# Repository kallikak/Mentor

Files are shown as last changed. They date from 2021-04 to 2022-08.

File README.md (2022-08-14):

# Constructive Synthesis Mentor

A complete single board polyphonic synthesiser based on a Teensy 4.0 and Teensy Audio Shield. Called Mentor due to its focus as an instrument for learning subtractive synthesis. <a href="http://thewessens.net/synthbook/#constructive-synthesis">Constructive Synthesis</a> is the associated website covering the basics for learning subtractive synthesis.

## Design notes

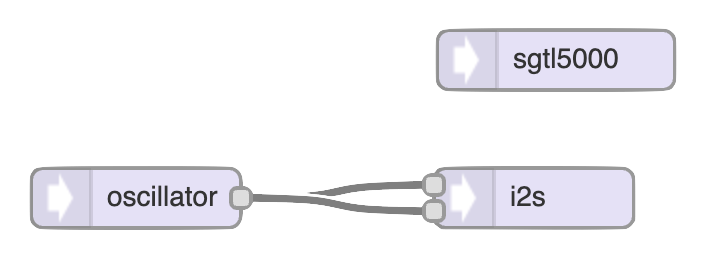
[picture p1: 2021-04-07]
teensy/SimpleOscillator.png

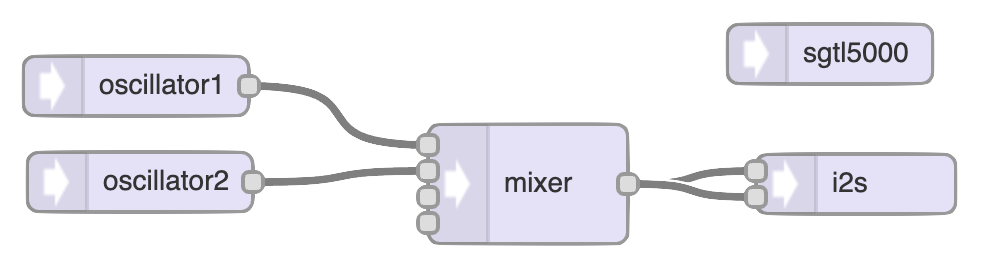
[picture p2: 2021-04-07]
teensy/Detune.png

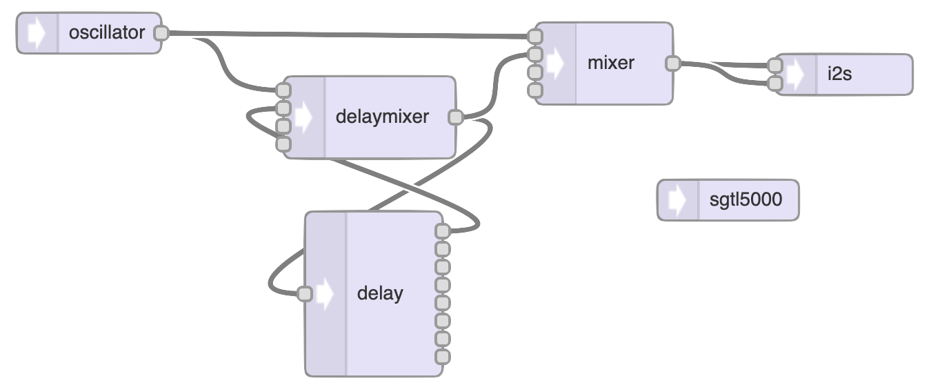
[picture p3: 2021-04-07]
teensy/Delay.png

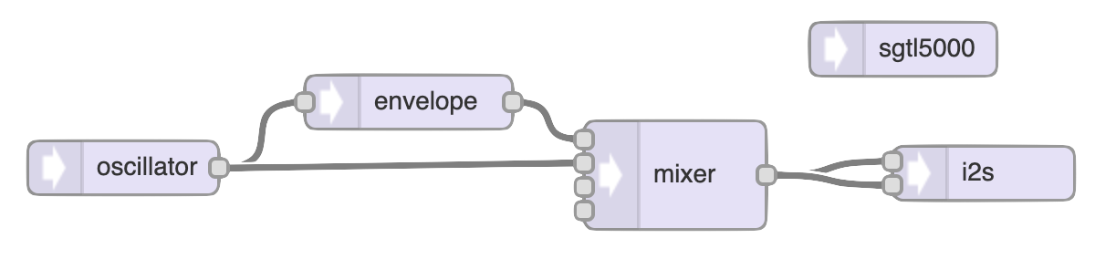
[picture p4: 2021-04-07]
teensy/ADSR.png

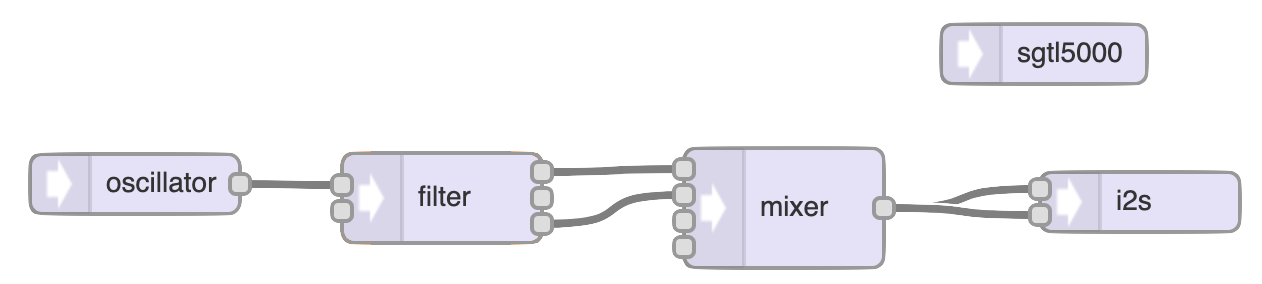
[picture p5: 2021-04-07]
teensy/Filter.png

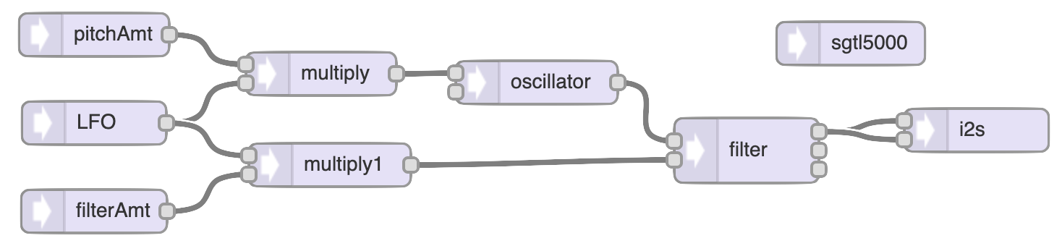
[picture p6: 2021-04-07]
teensy/LFO.png

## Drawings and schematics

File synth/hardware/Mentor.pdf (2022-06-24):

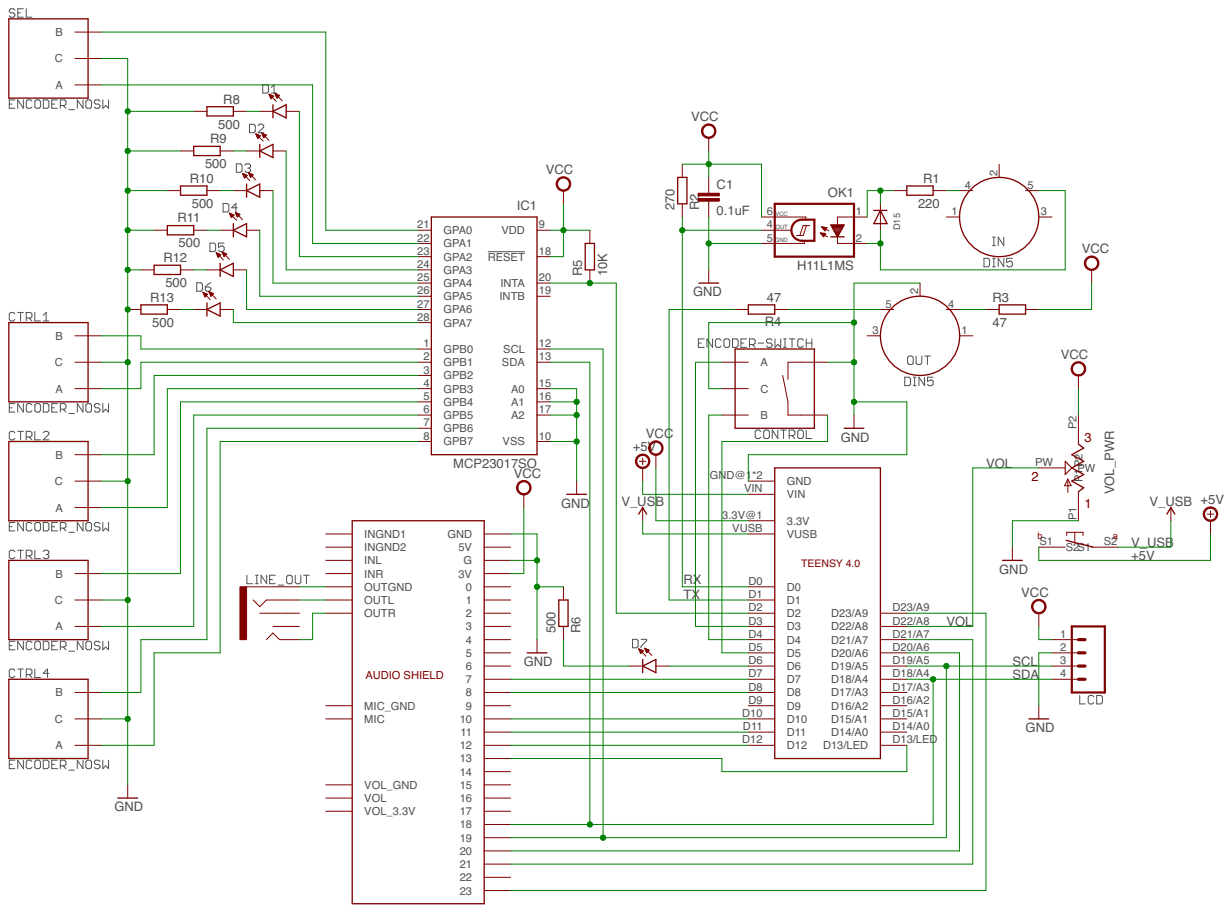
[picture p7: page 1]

VUSB

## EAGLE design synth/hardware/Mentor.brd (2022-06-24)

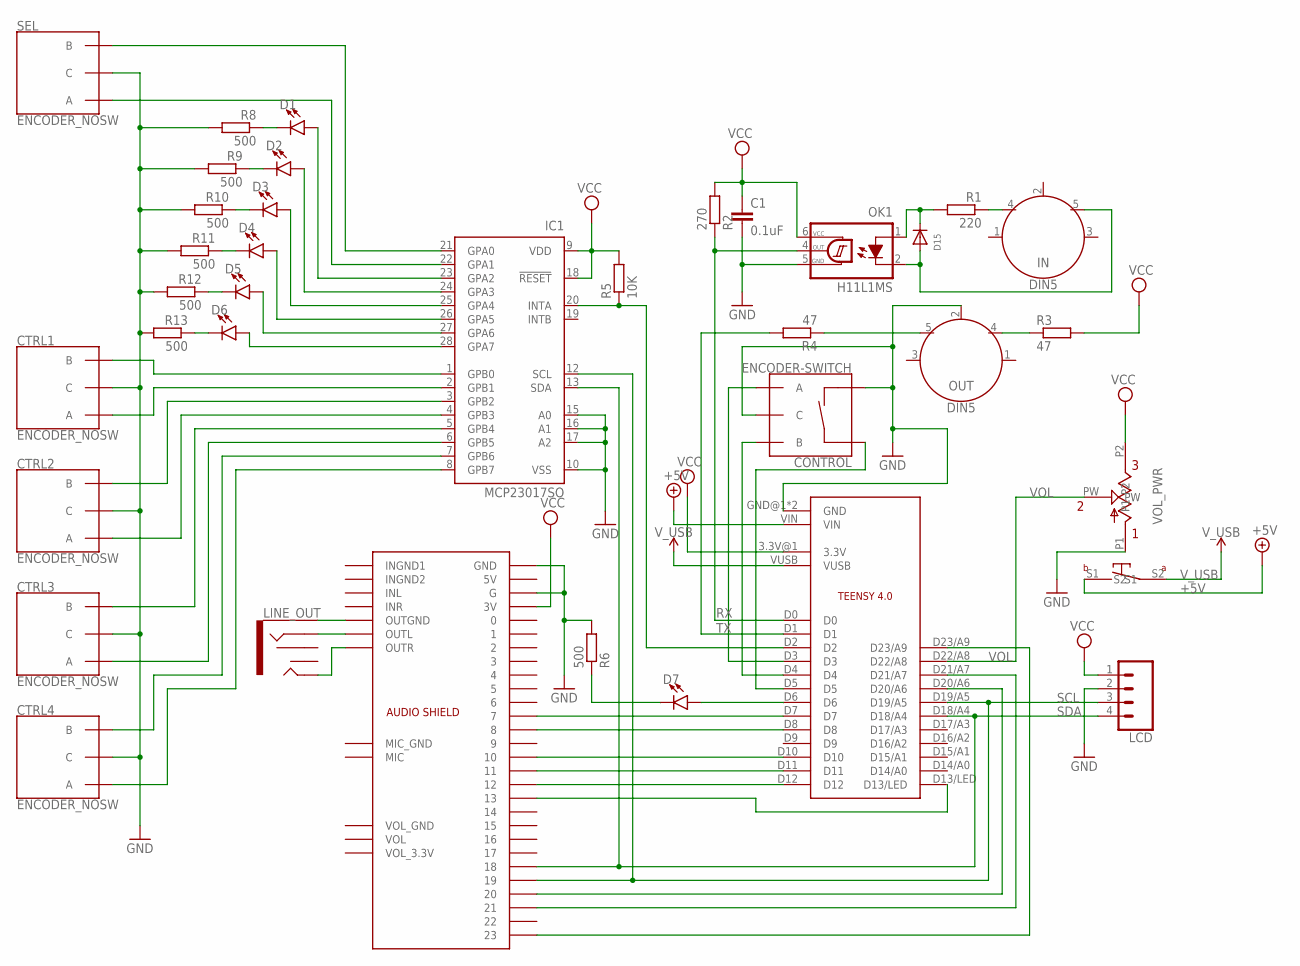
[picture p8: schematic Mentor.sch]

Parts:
C1: 0.1uF; C0603K
CONTROL: ENCODER-SWITCH; ROTARY_ENC_PLAIN
CTRL1, CTRL2, CTRL3, CTRL4: ENCODER_NOSW
D1, D2, D3, D4, D5, D6, D7: LED3MM; LED_3MM
D15: DIODESOD-123; SOD-123
IC1: MCP23017SO; SO28W
IN: DIN5; DIN5-RA-PTH
LCD: CONN_04LONGPADS; 1X04_LONGPADS
LINE_OUT: AUDIO_JACK_3.5MM_PTH; AUDIO-JACK
OK1: H11L1MS; DIL6-SMD
OUT: DIN5; DIN5-RA-PTH
R1: 220; R0603
R2: 270; R0603
R3, R4: 47; R0603
R5: 10K; R0603
R6, R8, R9, R10, R11, R12, R13: 500; R0603
SEL: ENCODER_NOSW
U$2: TEENSY4.0_SIMPLE
U$3: AUDIO SHIELD; AUDIOSHIELD
VOL_PWR: 10K; RK097-SINGLE-W/SWITCH

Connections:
+5V: U$2.VIN, VOL_PWR.S1
GND: C1.2, CONTROL.C, CONTROL.SW-, CTRL1.C, CTRL2.C, CTRL3.C, CTRL4.C, IC1.10 (VSS), IC1.15 (A0), IC1.16 (A1), IC1.17 (A2), LCD.2, OK1.5 (GND), OUT.2, R6.2, R8.2, R9.2, R10.2, R11.2, R12.2, R13.2, SEL.C, U$2.GND@1 (GND), U$2.GND@2 (GND), U$3.G, U$3.GND, VOL_PWR.P1
MISO: U$2.D12, U$3.12
MOSI: U$2.D11, U$3.11
unnamed: IC1.21 (GPA0), SEL.B
unnamed: IC1.22 (GPA1), SEL.A
unnamed: CTRL1.B, IC1.1 (GPB0)
unnamed: CTRL1.A, IC1.2 (GPB1)
unnamed: CTRL2.B, IC1.3 (GPB2)
unnamed: CTRL2.A, IC1.4 (GPB3)
unnamed: CTRL3.B, IC1.5 (GPB4)
unnamed: CTRL3.A, IC1.6 (GPB5)
unnamed: CTRL4.B, IC1.7 (GPB6)
unnamed: CTRL4.A, IC1.8 (GPB7)
unnamed: OUT.5, R4.1
unnamed: U$2.D20/A6, U$3.20
unnamed: U$2.D21/A7, U$3.21
unnamed: U$2.D23/A9, U$3.23
unnamed: U$2.D10, U$3.10
unnamed: U$2.D7, U$3.7
unnamed: U$2.D8, U$3.8
unnamed: IC1.20 (INTA), R5.1, U$2.D2
unnamed: D6.K (C), R13.1
unnamed: D1.K (C), R8.1
unnamed: D6.A, IC1.28 (GPA7)
unnamed: D7.K (C), R6.1
unnamed: D7.A, U$2.D6
unnamed: D2.K (C), R9.1
unnamed: D3.K (C), R10.1
unnamed: D3.A, IC1.25 (GPA4)
unnamed: CONTROL.A, U$2.D3
unnamed: CONTROL.B, U$2.D4
unnamed: CONTROL.SW+, U$2.D5
unnamed: D4.K (C), R11.1
unnamed: D5.K (C), R12.1
unnamed: D15.A, IN.5, OK1.2 (C)
unnamed: D15.C, OK1.1 (A), R1.2
unnamed: IN.4, R1.1
unnamed: LINE_OUT.SLEEVE, U$3.OUTGND
unnamed: OUT.4, R3.1
unnamed: LINE_OUT.RING, U$3.OUTL
unnamed: LINE_OUT.TIP, U$3.OUTR
RX: OK1.4 (OUT), R2.1, U$2.D0
SCK: U$2.D13/LED, U$3.13
SCL: IC1.12 (SCL), LCD.3, U$2.D19/A5, U$3.19
SDA: IC1.13 (SDA), LCD.4, U$2.D18/A4, U$3.18
SEL1: D1.A, IC1.23 (GPA2)
SEL2: D2.A, IC1.24 (GPA3)
SEL4: D4.A, IC1.26 (GPA5)
SEL5: D5.A, IC1.27 (GPA6)
TX: R4.2, U$2.D1
VCC: C1.1, IC1.9 (VDD), IC1.18 (!RESET), LCD.1, OK1.6 (VCC), R2.2, R3.2, R5.2, U$2.3.3V@1 (3.3V), U$3.3V, VOL_PWR.P2
VOL: U$2.D22/A8, VOL_PWR.PW
V_USB: U$2.VUSB, VOL_PWR.S2

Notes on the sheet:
AUDIO SHIELD

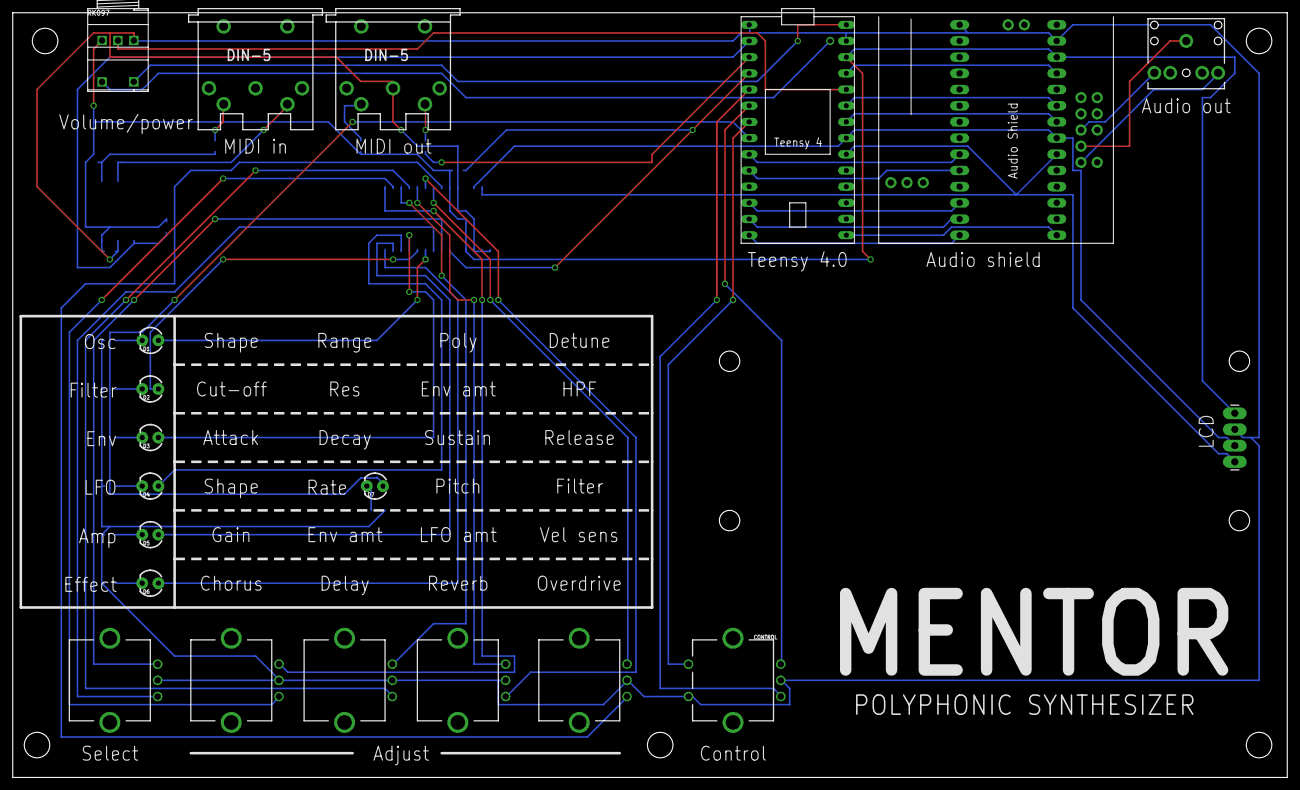
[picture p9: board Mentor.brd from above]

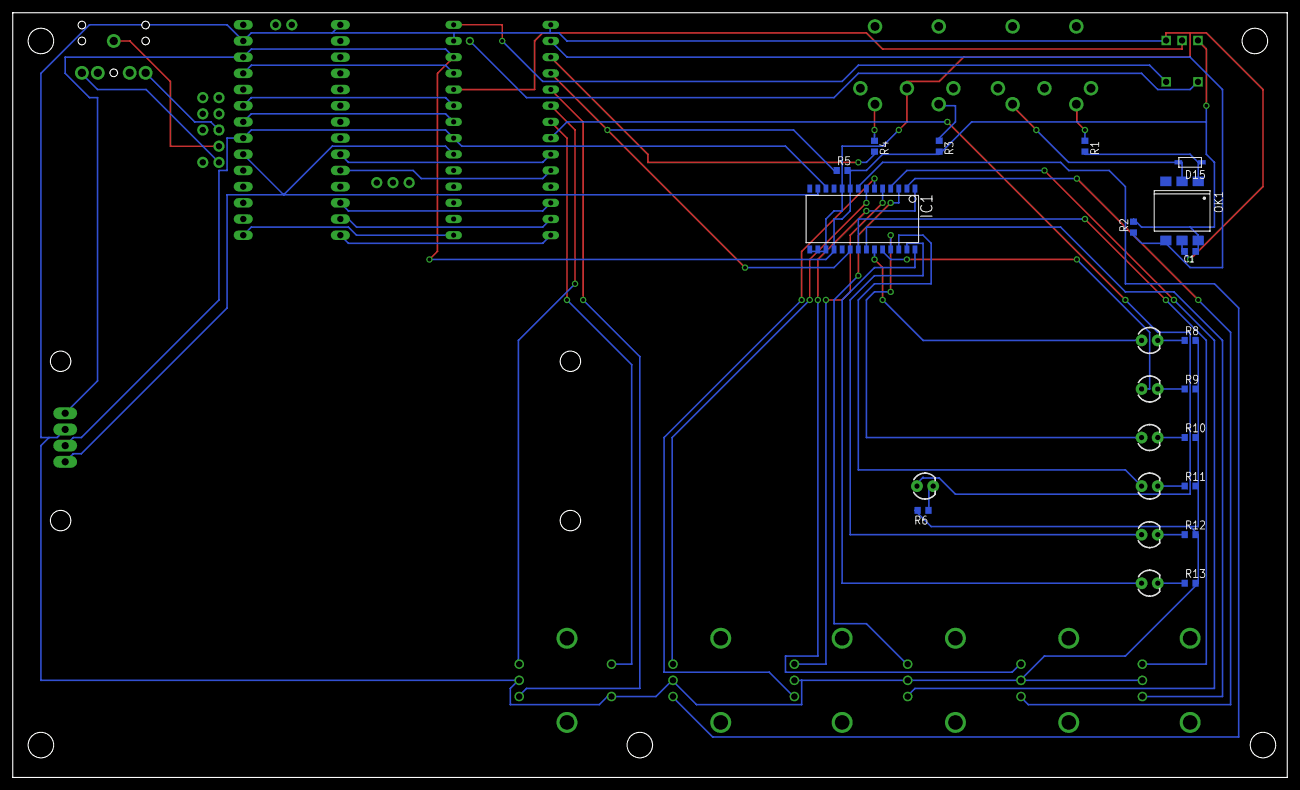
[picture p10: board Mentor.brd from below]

Board: 2 copper layers, 200.0 x 120.0 mm, 36 parts (16 on the bottom side), 54 nets.

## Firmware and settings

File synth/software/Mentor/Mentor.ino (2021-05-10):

#include <Wire.h>
#include <ctype.h>

#include "Config.h"
#include "Control.h"
#include "Controls.h"
#include "Demo.h"
#include "LCD.h"
#include "MIDIManager.h"
#include "Presets.h"
#include "Synth.h"
#include "Voice.h"

#define LFO_LED 6

Synth *synth;

void setup() 
{
  Serial.begin(9600);
  delay(1000);
  srand((analogRead(A0) << 10) + analogRead(A1));  // unused pins
  
  setupLCD();
  setupControls();
  setupControl();
  initDemo();
  
  pinMode(LFO_LED, OUTPUT);
  digitalWrite(LFO_LED, LOW);

  synth = new Synth();
  loadPreset(getSavedStartupPreset());
  delay(500);
  writeParamString(1, "Loading", getPresetName(getSavedStartupPreset()));
  delay(1000);
  synth->loadConfig(config);
  
  setupMIDI();
  printConfig(config);
  
  Serial.println("Setup done");
}

int loopcount = 0;
bool monitorlevel = false;
void monitorPeak();
void loop() 
{
  static bool led = false;
  checkControls(loopcount++);
  checkControl();
  
  if (monitorlevel && loopcount % 200 == 0)
  {
    monitorPeak();
  }
  
  checkMIDI();
  if (synth->checkFlashLFO())
  {
    led = !led;
    digitalWrite(LFO_LED, led);
  }
  checkDemo();
  if (Serial.available())
  {
    char c = Serial.read();
    if (iscntrl(c))
    {
      // ignore control data 
    }
    else if (c == 'p')
    {
      printConfig(config);
    }
    else if (c == '1')
    {
      Serial.println("Playing 1 note");
      playNote(55, 127);
    }
    else if (c == '2')
    {
      Serial.println("Playing 2 notes");
      playNote(55, 127);
      playNote(62, 127);
    }
    else if (c == '5')
    {
      Serial.println("Playing 5 notes");
      playNote(55, 127);
      playNote(59, 127);
      playNote(62, 127);
      playNote(67, 127);
      playNote(69, 127);
    }
    else if (c == '0')
    {
      Serial.println("Lifting notes");
      releaseNote(55);
      releaseNote(59);
      releaseNote(62);
      releaseNote(67);
      releaseNote(69);
    }
    else if (c == 'm')
    {
      Serial.print("Max memory usage: ");
      Serial.println(AudioMemoryUsageMax());
    }
    else if (c == 't')
    {
      Serial.print("MCU Temperature: ");
      Serial.println(tempmonGetTemp());
    }
    else if (c == 'v')
    {
      monitorlevel = !monitorlevel;
      Serial.print("Output level monitor ");
      Serial.println(monitorlevel ? "on" : "off");
    }
    else if (c == 'h')
    {
      Serial.println("========");
      Serial.println("Commands");
      Serial.println("========");
      Serial.println("p:\tPrint current config");
      Serial.println("m:\tPrint max audio memory usage");
      Serial.println("v:\tToggle output volume level monitor");
      Serial.println("t:\tPrint MCU temperature");
      Serial.println("h:\tPrint this message");
    }
    else if (c != '\r' && c != '\n' && !isspace(c))
    {
      Serial.println("Available commands: pmvth");
      Serial.println("Type h for help");
    }
    while (Serial.available())
      Serial.read();
  }
}

/*
 * BUGS
 *  - Something strange happens when amp env amount is 0
 * TODO
 *  - Refine levels
 */

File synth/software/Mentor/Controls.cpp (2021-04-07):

#include "Adafruit_MCP23017.h"
#include "Rotary.h"
#include <Bounce2mcp.h>

#include "Config.h"
#include "Controls.h"
#include "LCD.h"
#include "Utility.h"
#include "Synth.h"
#include "MIDIManager.h"

#define NUM_SELECT  6
class BounceMcp;

typedef struct
{
  int pinA;
  int pinB;
  uint16_t mask;
  bool halfstate;
  uint8_t _state;
  int minval[NUM_SELECT];
  int maxval[NUM_SELECT];
  BounceMcp *debouncer;
} encoder;

void setSelectLed(int led);
void showSelectSummary(int selected, bool addRow1);
void handleEncoderTurn(int i, int d);
void handleEncoderPress(int i);

int selected = 0;

#define SELECT_OSC  0
#define SELECT_FLT  1
#define SELECT_ENV  2
#define SELECT_LFO  3
#define SELECT_AMP  4
#define SELECT_EFF  5

int lastupdatemillis = 0;
bool summaryDone = false;

bool isFrequencyMode = false;
float droneFreq = 440;
  
Adafruit_MCP23017 *expander = NULL;

int selleds[] = { 2, 3, 4, 5, 6, 7 };

#define NUM_ENCODERS 6

encoder encoders[] = {
  { 0,  1, 0x0003, false, R_START, {0, 0, 0, 0, 0, 0}, {5, 5, 5, 5, 5, 5}, NULL },
  // Shape, Cutoff, Attack, LFO_Shape, Gain, Chorus
  { 8,  9, 0x0300, false, R_START, {0, 0, 0, 0, 0, 0}, {250, 127, 127, 6, 127, 15}, NULL },
  // Range, Res, Decay, Rate, Amp_Env_Amt, Delay
  {10, 11, 0x0700, false, R_START, {0, 0, 0, 0, 0, 0}, {3, 127, 127, 127, 127, 15}, NULL },
  // Poly, Flt_Env_Amt, Sustain, Pitch, LFO_Amt, Reverb
  {12, 13, 0x3000, false, R_START, {0, -63, 0, 0, 0, 0}, {POLYMAX, 64, 127, 127, 127, 15},  NULL },
  // Detune, HPF, Release, LFO_Flt, Vel_sens, Overdrive
  {14, 15, 0x7000, false, R_START, {0, 0, 0, 0, 0, 0}, {50, 127, 127, 127, 127, 15}, NULL }
};

#define SELECT_ENC 0

uint16_t blockMillis = 0;

void setupEncoders()
{
  int j;
  expander = new Adafruit_MCP23017();
  expander->begin((uint8_t)0);
  for (j = 0; j < NUM_ENCODERS; ++j)
  {
    encoder *enc = &encoders[j];
    expander->pinMode(enc->pinA, INPUT);
    expander->pullUp(enc->pinA, HIGH); // turn on a 100K pullup internally
    expander->pinMode(enc->pinB, INPUT);
    expander->pullUp(enc->pinB, HIGH); // turn on a 100K pullup internally
  }
  for (j = 0; j < NUM_SELECT; ++j)
  {
    int p = selleds[j];
    expander->pinMode(p, OUTPUT);
    expander->digitalWrite(p, LOW);
  }
}

static int lastencoder = -1;
static long lastencodermillis = -1;

#define MIN_ENC_TIME 50
#define MAX_ENC_TIME 200
#define MAX_ENC_ACCEL 16

void checkEncoders(unsigned long now)
{
  uint16_t vals = expander->readGPIOAB();
  for (int i = 0; i < NUM_ENCODERS; ++i)
  {
    encoder *e = &encoders[i]; 
    uint16_t val = vals;
    val >>= e->pinA;
    int p0 = val & 0x0001;
    int p1 = (val & 0x0002) >> 1;
    uint8_t pinstate = (p1 << 1) | p0;  
    if (e->halfstate)
      e->_state = ttable_half[e->_state & 0xf][pinstate];
    else
      e->_state = ttable[e->_state & 0xf][pinstate]; 
    int d;      
    if ((e->_state & 0x30) == DIR_CW)
      d = 1;
    else if ((e->_state & 0x30) == DIR_CCW)
      d = -1;
    else
      d = 0;

    if (d)
    {
      // add some acceleration for the encoders unless the value range is small
      bool accel = e->maxval[selected] - e->minval[selected] > 20;
      if (accel)
      {
        if (lastencoder != i)
        {
          lastencoder = i;
          lastencodermillis = -1;
        }
        else 
        {
          lastencoder = i;
          long delta = now - lastencodermillis;
          int factor;
          if (delta >= MAX_ENC_TIME)
            factor = 1;
          else if (delta <= MIN_ENC_TIME)
            factor = MAX_ENC_ACCEL;
          else
            factor = MAX_ENC_ACCEL - round(1.0 * (delta  - MIN_ENC_TIME) / (MAX_ENC_TIME - MIN_ENC_TIME) * (MAX_ENC_ACCEL - 1));
          d *= factor;
          lastencodermillis = now;
        }
      }
      handleEncoderTurn(i, d);
      lastupdatemillis = now;
      summaryDone = false;
    }
  }
}
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

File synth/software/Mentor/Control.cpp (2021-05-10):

#include <Bounce2.h>

#include "Config.h"
#include "Control.h"
#include "Controls.h"
#include "Demo.h"
#include "LCD.h"
#include "MIDIManager.h"
#include "Rotary.h"
#include "Presets.h"
#include "Synth.h"

#define CONTROL_A  3
#define CONTROL_B  4
#define CONTROL_SW 5
#define LONG_MILLIS 1000

typedef enum
{
  CTRL_PRESET,  // for loading ROM or user presets
  CTRL_USER,    // for saving user presets
  CTRL_MIDICLK, // toggling external clock
  CTRL_DEMO,    // play or stop demo
  CTRL_PANIC,   // all MIDI notes off
  CTRL_AFTERTOUCH
} control_state;
#define NUM_STATES 6
#define CTRL_LAST CTRL_AFTERTOUCH

void checkSwitch();
void controlClick();
void controlLongPress();
void controlTurned(int d, bool btnState);
void selectValue();
void selectState();

static control_state ctrl_state = CTRL_LAST;
static int ctrl_val = 0;
static bool state_selected = false;

static bool halfstate = false;
static uint8_t _state;

static Bounce debouncer = Bounce(); 
static long falltimeP = -1;
static bool longpressP = false;

int getLastStateValue()
{
  switch (ctrl_state)
  {
    case CTRL_PRESET:
      return getLastPresetIndex() + 1;
    case CTRL_MIDICLK:
      return synth->getLFOSync() + 1;
    case CTRL_USER:
      return getLastUserPresetIndex();
    case CTRL_DEMO:
      return demoIsPlaying() ? 1 : 0;
    case CTRL_AFTERTOUCH:
      return getAftertouch() ? 1 : 0;
    default:
      return 0;
  }
}

const char *getStateString(control_state state)
{
  switch (state)
  {
    case CTRL_PRESET:
      return "Presets";
    case CTRL_USER:
      return "Save";
    case CTRL_MIDICLK:
      return "LFO Sync";
    case CTRL_DEMO:
      return "Demo";
    case CTRL_PANIC:
      return "Panic";
    case CTRL_AFTERTOUCH:
      return "Aftertouch";
    default:
      return "";
  }
}

Str16 tempStr;
const char *getValueString(control_state state, int ctrl_val)
{
  if (ctrl_val == 0)
    return "Cancel";
  switch (state)
  {
    case CTRL_PRESET:
    {
      if (ctrl_val <= NUM_PRESETS)
        return getPresetName(ctrl_val - 1);
      else
      {
        sprintf(tempStr, "User %d", ctrl_val - NUM_PRESETS);
        return tempStr;
      }
    }
    case CTRL_USER:
    {
      sprintf(tempStr, "User %d", ctrl_val);
      return tempStr;
    }
    case CTRL_MIDICLK:
      return getLFOSyncFactorString((LFOSync_t)((ctrl_val - 1) % NUM_CLOCK_FACTORS));
    case CTRL_DEMO:
      return getDemoDescription(ctrl_val);
    case CTRL_PANIC:
      return "Send notes off";
    case CTRL_AFTERTOUCH:
      return getAftertouch() ? "Turn off" : "Turn on";
  }
  return "<N/A>";
}

void setupControl()
{
  pinMode(CONTROL_A, INPUT_PULLUP);
  pinMode(CONTROL_B, INPUT_PULLUP);
  pinMode(CONTROL_SW, INPUT_PULLUP);
  debouncer.attach(CONTROL_SW);
  debouncer.interval(50);
}

void checkControl()
{
  checkSwitch();
  bool buttonState = debouncer.read();
  int p0 = digitalRead(CONTROL_A);
  int p1 = digitalRead(CONTROL_B);
  uint8_t pinstate = (p0 << 1) | p1;
  if (halfstate)
    _state = ttable_half[_state & 0xf][pinstate];
  else
    _state = ttable[_state & 0xf][pinstate]; 
  if ((_state & 0x30) == DIR_CW)
    controlTurned(1, buttonState);
  else if ((_state & 0x30) == DIR_CCW)
    controlTurned(-1, buttonState);
}

void checkSwitch()
{
  debouncer.update();
  if (debouncer.fell())
  {
    longpressP = false;
    falltimeP = millis();
  }
  else if (falltimeP > 0 && debouncer.rose())
  {
    if (!longpressP) 
      controlClick();
    longpressP = false;
    falltimeP = -1;
  }
  else if (falltimeP > 0 && (millis() - falltimeP > LONG_MILLIS))
  {
    if (!longpressP)
    {
      controlLongPress();
      longpressP = true;
      falltimeP = -1;
    }
  }
}

void controlClick()
{
  lastupdatemillis = millis();
  if (state_selected)
    selectValue();
  else
    selectState();
  state_selected = !state_selected;
}

void controlLongPress()
{
}

void controlTurned(int d, bool btnState)
{
  lastupdatemillis = millis();
  if (state_selected)
  {
    ctrl_val += d;
    switch (ctrl_state)
    {
      case CTRL_PRESET:
        ctrl_val = max(0, min(NUM_USER + NUM_PRESETS, ctrl_val));
        break;
      case CTRL_USER:
        ctrl_val = max(0, min(NUM_USER, ctrl_val));
        break;
      case CTRL_MIDICLK:
        ctrl_val = max(0, min(NUM_CLOCK_FACTORS, ctrl_val));
        break;
      case CTRL_DEMO:
        ctrl_val = max(0, min(demoIsPlaying() ? 2 : 4, ctrl_val));
        break;
      case CTRL_PANIC:
      case CTRL_AFTERTOUCH:
        break;  // nothing to do
    }
    writeParamString(0, " ", getStateString(ctrl_state));
    writeParamString(1, ">", getValueString(ctrl_state, ctrl_val));
  }
  else
  {
    ctrl_state = (control_state)((ctrl_state + d + NUM_STATES) % NUM_STATES); 
    ctrl_val = getLastStateValue();
    writeParamString(0, ">", getStateString(ctrl_state));
    writeParamString(1, " ", getValueString(ctrl_state, ctrl_val));
  }
}

void selectState()
{
  ctrl_val = getLastStateValue();
  writeParamString(0, " ", getStateString(ctrl_state));
  writeParamString(1, ">", getValueString(ctrl_state, ctrl_val));
}

void selectValue()
{
  writeParamString(0, ">", getStateString(ctrl_state));
  writeParamString(1, " ", getValueString(ctrl_state, ctrl_val));
  if (ctrl_val == 0)
    return;  // Cancel
  switch (ctrl_state)
  {
    case CTRL_PRESET:
      loadPreset(ctrl_val - 1);
      break;
    case CTRL_USER:
      if (ctrl_val)
        updateUserPreset((byte)ctrl_val - 1);
      break;
    case CTRL_MIDICLK:
      synth->setLFOSync((LFOSync_t)(ctrl_val - 1));
      break;
    case CTRL_DEMO:
      if (demoIsPlaying())
        stopDemo();
      else
        startDemo(ctrl_val);
      break;
    case CTRL_PANIC:
      resetMIDI();
      break;
    case CTRL_AFTERTOUCH:
      setAftertouch(!getAftertouch());
      break;
  }
  writeParamString(1, " ", getValueString(ctrl_state, ctrl_val));
}

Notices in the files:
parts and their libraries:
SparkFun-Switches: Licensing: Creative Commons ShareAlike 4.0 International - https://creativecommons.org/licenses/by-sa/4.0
